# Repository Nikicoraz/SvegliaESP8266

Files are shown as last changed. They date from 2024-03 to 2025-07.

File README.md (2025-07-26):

# Sveglia ESP8266
Questa è una sveglia progettata da zero da me

### Firmware
Il firmware della sveglia è scritto in Arduino

### Hardware
L'hardware della sveglia è composto da un ESP8266, un buzzer polarizzato con un passo di 6.6mm, un display LCD 16x4 con un adattatore da parallelo a seriale I2C, un encoder e un alimentatore

### Progettazione hardware
La progettazione dell'hardware è stata svolta nel software KiCad

### Schematica
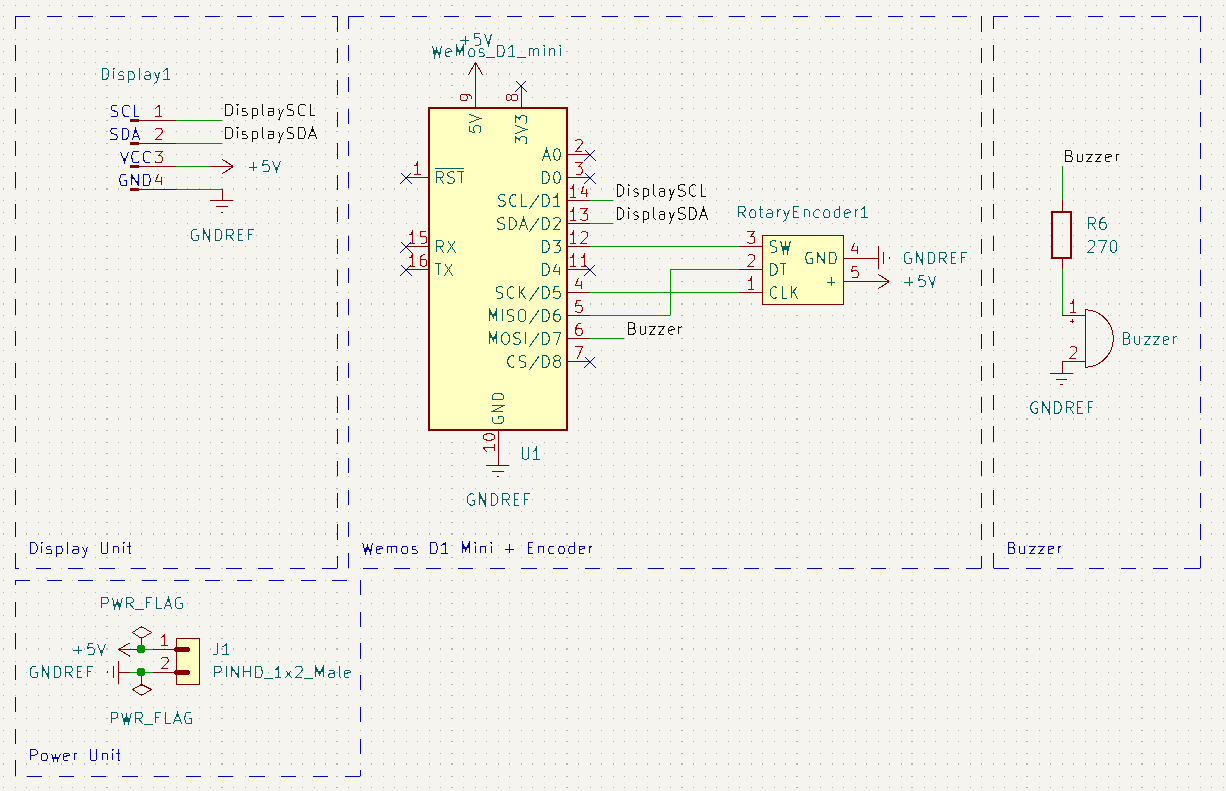
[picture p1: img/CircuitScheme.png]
Schematica


### PCB
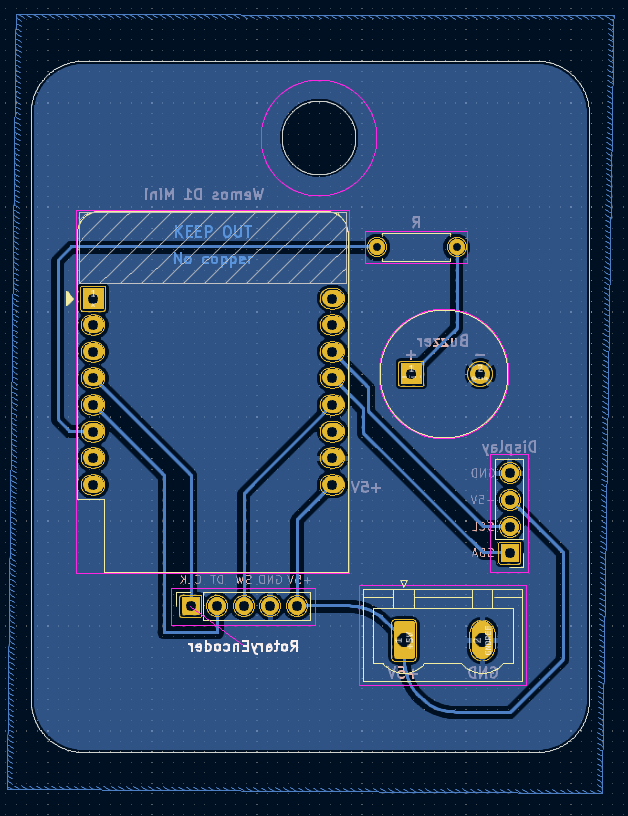
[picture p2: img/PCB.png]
PCB


Per la stampa del PCB ho utilizzato il sito [PCBWay](https://www.pcbway.com/)
### Creazione della sveglia
Dopo aver acquisito i componenti necessari e il circuito stampato, serve creare un file include/secrets.h dove bisogna inserire l'SSID e la password del Wifi e dell'hotspot e flashare l'ESP

Es.
```C
// include/secrets.h

#define SECRET_SSID "<SSID>";
#define SECRET_PASSWD "<Password>";
#define AP_PASSWD "<Password>"
```

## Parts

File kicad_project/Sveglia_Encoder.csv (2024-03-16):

# | Reference | Qty | Value | Footprint | DNP
1 | BZ1 | 1 | Buzzer
2 | D1 | 1 | LED
3 | J1 | 1 | Conn_01x04_Pin
4 | R1, R2, R3, R4, R5, R6 | 6 | 270
5 | SW1, SW2, SW3, SW4 | 4 | SW_SPST
6 | U1 | 1 | WeMos_D1_mini | Module:WEMOS_D1_mini_light

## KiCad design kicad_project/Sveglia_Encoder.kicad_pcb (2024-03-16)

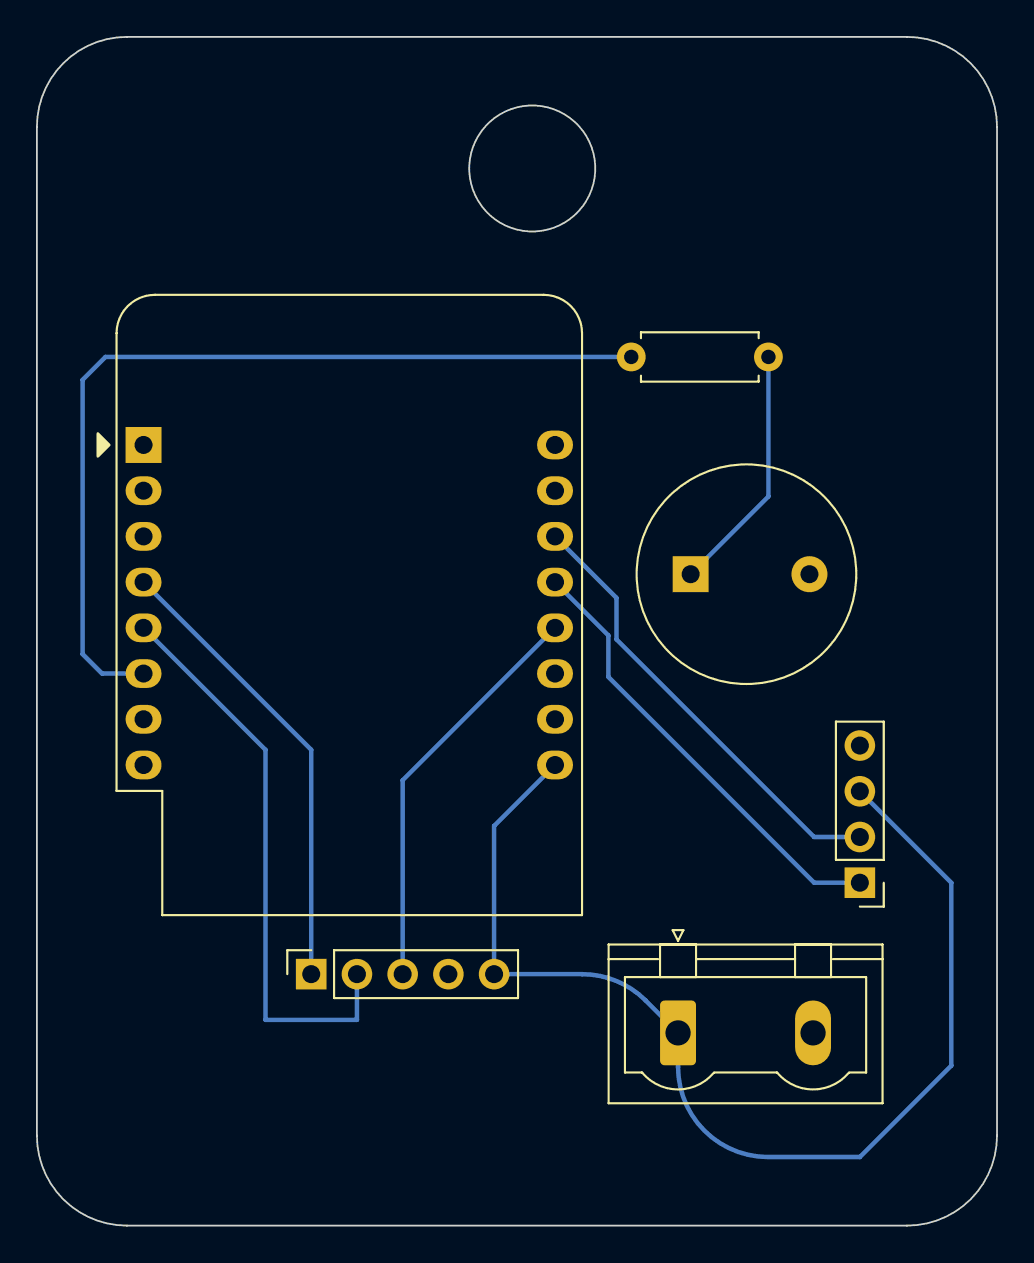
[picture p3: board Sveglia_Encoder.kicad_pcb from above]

Board: 2 copper layers, 53.3 x 66.0 mm, 6 parts (0 on the bottom side), 9 nets.

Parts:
+5V: PINHD_1x2_Male; PhoenixContact_GMSTBVA_2,5_2-G_1x02_P7.50mm_Vertical
BZ1: Buzzer; Buzzer_12x9.5RM6.6
Display: Display; PinHeader_1x04_P2.54mm_Vertical
R: 270; R_Axial_DIN0207_L6.3mm_D2.5mm_P7.62mm_Horizontal
RotaryEncoder: PinSocket_1x05_P2.54mm_Vertical
Wemos D1 Mini: WeMos_D1_mini; WEMOS_D1_mini_light

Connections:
+5V: +5V.1, Display.3, RotaryEncoder.5 (+), Wemos D1 Mini.9 (5V)
/Buzzer: R.1, Wemos D1 Mini.6 (MOSI/D7)
/DisplaySCL: Display.1, Wemos D1 Mini.14 (SCL/D1)
/DisplaySDA: Display.2, Wemos D1 Mini.13 (SDA/D2)
GNDREF: +5V.2, BZ1.2 (+), Display.4, RotaryEncoder.4 (GND), Wemos D1 Mini.10 (GND)
unnamed: BZ1.1 (-), R.2
unnamed: RotaryEncoder.1 (CLK), Wemos D1 Mini.4 (SCK/D5)
unnamed: RotaryEncoder.2 (DT), Wemos D1 Mini.5 (MISO/D6)
unnamed: RotaryEncoder.3 (SW), Wemos D1 Mini.12 (D3)

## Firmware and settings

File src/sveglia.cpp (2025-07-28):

/*

  Author: Nicola Corato
  Email: nicolacorato05@gmail.com

*/

#define SW 0    // D3 = GPIO0
#define DT D6
#define CLK D5

#include <LiquidCrystal_I2C.h>
#include <NTPClient.h>
#include <ESP8266WiFi.h>
#include <WiFiUdp.h>
#include <EEPROM.h>
#include <ArduinoOTA.h>
#include <time.h>
#include <cmath>
#include <ESP8266mDNS.h>

#include "secrets.h"
#include "menu.h"
#include "alarms.h"
#include "webserver.h"

const char* SSID = SECRET_SSID;
const char* PASSWD = SECRET_PASSWD;

// Time zone offset
const long utcOffsetInSeconds = 3600;
const bool considerLegalHour = true;

// Global time variables
byte seconds = 0;
byte minutes = 0;
byte hours = 0;
byte day = 0;
unsigned long ntpEpochTime;
unsigned long ntpStart;
bool timeSetManually = false;

char daysOfTheWeek[7][12] = { "Sunday", "Monday", "Tuesday", "Wednesday", "Thursday", "Friday", "Saturday" };

// For unset hour set to 255
byte alarmTimes[7][2] = { {255,255}, {255,255}, {255,255}, {255,255}, {255,255}, {255,255}, {255,255} };
byte nextAlarm[2] = {255, 255};
int nextDay = -1;

bool dismissNextAlarm = false;
bool alarmSounded = false;
int selectedAlarm = 0;

// Define NTP Client to get time
WiFiUDP ntpUDP;
NTPClient timeClient(ntpUDP, "europe.pool.ntp.org", utcOffsetInSeconds);

// LCD setup
const byte columns = 20;
const byte rows = 4;
LiquidCrystal_I2C lcd(0x27, columns, rows);
byte isBacklightOn = 0;
long long int backlightTimer = millis();

// Menu
MenuItem* currentMenu = nullptr;
int currentMenuLength;
int menuOption = 0;
int firstMenuOption = 0;
byte isMenuOpen = false;
int genericCouter;
bool genericCount = false;
bool genericDelay = false;
bool notConnectedMode = false;

//
// --- GENERAL FUNCTIONS ---
//

/*
  -- EEPROM STRUCTURE --
  0 (byte): EEPROM init value
  1-16 (byte[]): alarmTimes
  17-19 (byte[]): nextAlarm
  20-24 (int): nextDay
  24-28(int): selected alarm
  29 (byte): networkOverride
  29-???: networkOverrideSettings

*/

// 79 is a random prime number check
const byte EEPROMCheckValue = 79;

void generalSaveCheck(){
  byte temp;
  EEPROM.get(0, temp);
  if(temp != EEPROMCheckValue){
    EEPROM.put(0, EEPROMCheckValue);
  }
}

bool saveAlarmsToEEPROM(){
  generalSaveCheck();
  EEPROM.put(1, alarmTimes);
  EEPROM.put(17, nextAlarm);
  EEPROM.put(20, nextDay);
  return EEPROM.commit();
}

bool saveAlarmThemeToEEPROM(){
  generalSaveCheck();
  EEPROM.put(24, selectedAlarm);
  return EEPROM.commit();
}

void loadAlarmsFromEEPROM(){
  byte check = 0;
  if(EEPROM.get(0, check)){
    if(check == EEPROMCheckValue){
      // Alarm times
      EEPROM.get(1, alarmTimes);
      EEPROM.get(17, nextAlarm);
      EEPROM.get(20, nextDay);
  
      // Alarm theme
      EEPROM.get(24, selectedAlarm);
      Serial.println("Loaded alarms from EEPROM");
  
    }else{
      Serial.println("EEPROM not initialized yet");
    }
  }else{
    Serial.println("EEPROM reading failed");
  }
}

int calculateCenterTextColumnStart(int length) {
  return (columns - length) / 2;
}

int calculateCenterTextColumnStart(String text) {
  return calculateCenterTextColumnStart(text.length());
}

void centerPrint(String text, int row = 0) {
  lcd.setCursor(calculateCenterTextColumnStart(text), row);
  lcd.print(text);
}

void toggleBacklight() {
  isBacklightOn ? lcd.noBacklight() : lcd.backlight();
  isBacklightOn = !isBacklightOn;
}

void connectWifi();
bool setWifiFromWebserver(String, String);

void connectionFailed(){
  notConnectedMode = true;

  WiFi.mode(WIFI_AP);
  WiFi.softAP("ESPSveglia", AP_PASSWD);
  lcd.clear();
  centerPrint("IP: " + WiFi.softAPIP().toString(), 1);
  centerPrint("Press to set time", 2);
}

void connectWifi() {
  if(timeSetManually)
    return;

  int retries = 10;
  if(WiFi.status() != WL_CONNECTED){
    WiFi.mode(WIFI_STA);
    WiFi.setHostname("ESPSveglia"); 
    WiFi.begin(SSID, PASSWD);

    while (WiFi.status() != WL_CONNECTED && retries-- > 0) {
      delay(500);
      centerPrint("Retries: " + String(retries), 2);
      Serial.print(".");
    }

    if(retries == -1){
      centerPrint("Connection failed!", 1);
      connectionFailed();
      delay(1000);
      return;
    }else{
      notConnectedMode = false;
    }

    if(!MDNS.begin("espsveglia")) {     // Sets the esp mDNS to "espsveglia.local"
      Serial.println("Error setting up MDNS responder!");
    }

    Serial.print("Connected to ");
    Serial.println(SSID);
    Serial.print("Ip address: ");
    Serial.println(WiFi.localIP());
  }
}


// Will only be used with 31 day months
int lastSundayDay(int mday, int wday){
  if(wday != 0 && 31 - mday < 7){
    if(mday + (7 - wday) <= 31){
      return mday + (7 - wday);
    }else{
      return mday - wday;
    }
  }else{
    printf("Mday: %d\n", mday);
    printf("7 - wday: %d\naltro: %d\n", 7 - wday, 7 * (int)std::floor(((31 - mday) / 7) - 1));
    return mday + (7 - wday) + 7 * (int)std::floor(((31 - mday) / 7) - 1);
  }
}

void hourChange(){
  if (hours == 24) {
    hours = 0;
    day = (day + 1) % 7;
  }
}

void applyLegalHour(){
  hours += 1;
  hourChange();
}

void updateNTPTime() {
  if(timeSetManually)
    return;

  Serial.println("Updating time...");
  Serial.printf("Was %02d:%02d:%02d", hours, minutes, seconds);

  connectWifi();
  timeClient.begin();
  while(!timeClient.update()){
    delay(50);
    if(timeClient.forceUpdate()){   // Try to force the update since it only updates every 60 secs
      break;
    }
  } // Retry until the update succeds

  seconds = timeClient.getSeconds();
  minutes = timeClient.getMinutes();
  hours = timeClient.getHours();
  day = timeClient.getDay();
  ntpEpochTime = timeClient.getEpochTime();
  ntpStart = millis();

  if(considerLegalHour){
    // Legal hour >:(
    time_t current_time = timeClient.getEpochTime();
    struct tm* timeInfo = localtime(&current_time);
    int month = timeInfo->tm_mon;
    int mday = timeInfo->tm_mday;

    // Months have index 0
    if(month >= 3 || month <= 10){
      applyLegalHour();
    }else{
      // March
      
      int lastSunday = lastSundayDay(mday, day);
      if(month == 2){
        if(mday > lastSunday){
          applyLegalHour();
        }else{
          if(hours >= 2){
            applyLegalHour();
          }
        }
      }

      // October
      if(month == 9){
        if(mday < lastSunday){
          applyLegalHour();
        }else{
          if(hours < 3){
            applyLegalHour();
          }
        }
      }
    }
  }

  Serial.printf("Is now %02d:%02d:%02d", hours, minutes, seconds);

  timeClient.end();
}

void drawMainScreen();

void closeMenu(){
  isMenuOpen = false;
  if(((ntpEpochTime + ((millis() - ntpStart) / 1000)) / 60 ) % 60 != minutes){
    updateNTPTime();
  }
  drawMainScreen();
}

void renderMenu(MenuItem* menu, int firstOption, bool resetCursor = true) {
  lcd.clear();
  int bound = currentMenuLength > 4 ? (firstOption + 4) : currentMenuLength;
  for (int i = firstOption; i < bound; i++) {
    lcd.setCursor(0, i - firstOption);
    lcd.print(menu[i].getText().c_str());
    if (i == firstOption + 3) {
      lcd.setCursor(columns - 1, i - firstOption);
      lcd.write(0);
    }
  }
  if(resetCursor){
    lcd.cursor();
    lcd.setCursor(0, 0);
  }
}

int timeEquals(int h1, int min1, int h2, int min2){
  if(h1 == h2){
    if(min1 == min2){
      return 0;
    }else if(min1 > min2){
      return 1;
    }else{
      return -1;
    }
  }else if(h1 > h2){
    return 1;
  }else{
    return -1;
  }
}

int* getNextAlarmTime(){
  bool set = false;
  int* ret = (int*)malloc(sizeof(int) * 3);

  if(nextDay != -1){

    ret[0] = nextDay;
    ret[1] = nextAlarm[0];
    ret[2] = nextAlarm[1];
    set = true;
  }

  if(!set){
    for(int i = 0; i < 7; i++){
      int alarmHour, alarmMinutes, alarmDay;

      alarmDay = (i + day) % 7;
      alarmHour = alarmTimes[alarmDay][0];
      alarmMinutes = alarmTimes[alarmDay][1];
      if(alarmHour != 255 && (timeEquals(hours, minutes, alarmHour, alarmMinutes) == -1 || alarmDay != day)){
        ret[0] = alarmDay;
        ret[1] = alarmHour;
        ret[2] = alarmMinutes;
        set = true;
        break;
      }
    }
  }

  if(!set){
    ret[0] = 255;
  }
  
  return ret;
}

void drawMainScreen(){
  lcd.clear();
  lcd.noCursor();

  // The length of the time is always 8 chars with seconds
  lcd.setCursor(calculateCenterTextColumnStart(8), 0);
  lcd.printf("%02d:%02d:%02d", hours, minutes, seconds);


  int* nextAlarm = getNextAlarmTime();
  if(nextAlarm[0] != 255){
    centerPrint("Next alarm:", 2);
  
    char buffer[columns + 1];
    const char* dismissed = dismissNextAlarm ? "[D]" : "";
    sprintf(buffer, "%02d:%02d %s %s", nextAlarm[1], nextAlarm[2], daysOfTheWeek[nextAlarm[0]], dismissed);
    centerPrint(buffer, 3);
  }
  free(nextAlarm);
}

void changeMenu(MenuItem* menu, int length){
  currentMenu = menu;
  currentMenuLength = length;
  isMenuOpen = true;
  menuOption = 0;
  firstMenuOption = 0;
  renderMenu(currentMenu, 0);
}



void minuteChange(){
  alarmSounded = false;
  if (minutes == 60) {
    minutes = 0;
    hours += 1;
    hourChange();
  }
}

IRAM_ATTR void encoderRotateInterrupt() {
  if(genericCount){
    if(!genericDelay){    // This is because you can't do delays in functions nested too deep :(
      if(digitalRead(DT)){
        genericCouter--;
      }else{
        genericCouter++;
      }
      genericDelay = true;
    }
  }else if(isMenuOpen){
    // Change the current menu option
    if(digitalRead(DT)){
      if (menuOption > 0) menuOption--;
    }else{
      if(currentMenuLength - menuOption - 1 > 0){
        menuOption++;
      }
    }
    
    // Render menu based on the first menu option
    if(menuOption - firstMenuOption >= rows){
      firstMenuOption++;
      renderMenu(currentMenu, firstMenuOption, false);
    }else if(menuOption < firstMenuOption){
      firstMenuOption--;
      renderMenu(currentMenu, firstMenuOption, false);
    }
    lcd.setCursor(0, menuOption - firstMenuOption);
    delay(100);
  }
}

int abs(int x){
  return x > 0 ? x : -x;
}

void playAlarm(){
  MenuItem* prev;
  int length;
  if(isMenuOpen){
    prev = currentMenu;
    length = currentMenuLength;
  }
  alarmSounded = true;

  isBacklightOn = true;
  backlightTimer = millis();
  lcd.backlight();
  lcd.clear();
  centerPrint("WAKE UP!", 1);

  do{
    alarmArray[selectedAlarm]();
  }while(digitalRead(SW));

  if(isMenuOpen){
    changeMenu(prev, length);
  }
}

int* selectAlarmTime(String header = ""){
  int* ret = (int*)malloc(sizeof(int) * 2);
  genericCount = true;
  genericCouter = 0;
  lcd.clear();
  lcd.noCursor();
  if(header != ""){
    centerPrint(header);
  }else{
    centerPrint("Alarm time");
  }
  delay(200);

  int min = 0, h = 0;
  char buffer[5]; // "0" "0" ":" "0" "0" "\0"
  // Hour
  do{
    if(genericCouter < 0){
      genericCouter = 23;
    }
    h = genericCouter % 24;
    sprintf(buffer, "%02d:%02d", h, min);
    centerPrint(buffer, 1);
    delay(50);
    genericDelay = false;
  }while(digitalRead(SW));
  genericCouter = 0;
  delay(100);
  
  // Minutes
  do{
    if(genericCouter < 0){
      genericCouter = 59;
    }
    min = genericCouter % 60;
    sprintf(buffer, "%02d:%02d", h, min);
    centerPrint(buffer, 1);
    delay(50);
    genericDelay = false;
  }while(digitalRead(SW));

  genericCount = false;
  ret[0] = h;
  ret[1] = min;

  return ret;
}



void changeToMainMenu();

// 
//  --- CALLBACKS ---
//

void updateTimeCallback(){
  lcd.clear();
  lcd.noCursor();
  centerPrint("Updating time...", 1);

  updateNTPTime();
  closeMenu();
}

byte tempAlarm;
void confirmAlarmCallback();

void testAlarmCallback(){
  delay(200);
  int temp = selectedAlarm;
  selectedAlarm = tempAlarm;
  playAlarm();
  selectedAlarm = temp;
}

void changeAlarmSoundCallback();

MenuItem alarmConfirmMenu[3] = { MenuItem("Set", confirmAlarmCallback), MenuItem("Cancel", confirmAlarmCallback), MenuItem("Test", testAlarmCallback) };

const byte alarmSelectMenuLength = 7;
MenuItem alarmSelectMenu[alarmSelectMenuLength] = { MenuItem("Back", changeToMainMenu), MenuItem("Default alarm", changeAlarmSoundCallback),
                                MenuItem("Rapid fire alarm", changeAlarmSoundCallback), MenuItem("Uneven alarm", changeAlarmSoundCallback),
                                MenuItem("Scale alarm", changeAlarmSoundCallback), MenuItem("Double tone alarm", changeAlarmSoundCallback),
                                MenuItem("Complex Presents", changeAlarmSoundCallback) };

void confirmAlarmCallback(){
  if(menuOption == 0){
    selectedAlarm = tempAlarm;
    saveAlarmThemeToEEPROM();
  }
  changeMenu(alarmSelectMenu, alarmSelectMenuLength);
}

void changeAlarmSoundCallback(){
  tempAlarm = menuOption - 1;
  changeMenu(alarmConfirmMenu, 3);
}

void changeAlarmCallback(){
  changeMenu(alarmSelectMenu, alarmSelectMenuLength);
}

void alarmMenuBackCallback();
void setupAlarmDayCallback();
void removeAlarmDayCallback();

MenuItem alarmMenu[] = {
  MenuItem("Back", alarmMenuBackCallback), MenuItem("Weekdays", setupAlarmDayCallback), MenuItem("Weekend", setupAlarmDayCallback), MenuItem("Monday", setupAlarmDayCallback), 
  MenuItem("Tuesday", setupAlarmDayCallback),  MenuItem("Wednesday", setupAlarmDayCallback), MenuItem("Thursday", setupAlarmDayCallback), 
  MenuItem("Friday", setupAlarmDayCallback), MenuItem("Saturday", setupAlarmDayCallback),   MenuItem("Sunday", setupAlarmDayCallback)
};

MenuItem removeAlarmMenu[] = {
  MenuItem("Back", alarmMenuBackCallback), MenuItem("Weekdays", removeAlarmDayCallback), MenuItem("Weekend", removeAlarmDayCallback), MenuItem("Monday", removeAlarmDayCallback), 
  MenuItem("Tuesday", removeAlarmDayCallback),  MenuItem("Wednesday", removeAlarmDayCallback), MenuItem("Thursday", removeAlarmDayCallback), 
  MenuItem("Friday", removeAlarmDayCallback), MenuItem("Saturday", removeAlarmDayCallback),   MenuItem("Sunday", removeAlarmDayCallback)
};

void setupAlarmCallback(){
  changeMenu(alarmMenu, 10);
}

void setupAlarmDayCallback(){
  int selectedDay = menuOption - 1;
  int* time = selectAlarmTime();
  int h = time[0];
  int min = time[1];

  free(time);

  // Set the alarm and save to flash
  switch(selectedDay){
    case 0:
      for (int i = 0; i < 5; i++) {
        alarmTimes[i + 1][0] = h;
        alarmTimes[i + 1][1] = min;
      }
      break;
    case 1:
      alarmTimes[6][0] = h;
      alarmTimes[6][1] = min;
      alarmTimes[0][0] = h;
      alarmTimes[0][1] = min;
      break;
    case 2: case 3: case 4: case 5: case 6: case 7: case 8:
      alarmTimes[(selectedDay - 2 + 1) % 7][0] = h;
      alarmTimes[(selectedDay - 2 + 1) % 7][1] = min;
      break;
    default:
      Serial.println("How did we even get to this index??");
      exit(999);
      break;
  }

  saveAlarmsToEEPROM();
  Serial.println("Saved alarms to flash!");

  changeMenu(alarmMenu, 10);
}

void nextAlarmDaySelectCallback();

MenuItem nextAlarmTempMenu[2] = { MenuItem("Today", nextAlarmDaySelectCallback), MenuItem("Tomorrow", nextAlarmDaySelectCallback) };

void nextAlarmCallback(){
  int* time = selectAlarmTime();
  int h = time[0];
  int min = time[1];

  nextAlarm[0] = h;
  nextAlarm[1] = min; 
  free(time);

  changeMenu(nextAlarmTempMenu, 2);
}

//       |
//       |
//       ↓

void nextAlarmDaySelectCallback(){
  if(menuOption == 0){
    nextDay = day;
  }else{
    nextDay = (day + 1) % 7;
  }

  saveAlarmsToEEPROM();
  changeToMainMenu();
}

void mainTestAlarmCallback(){
  delay(200);
  playAlarm();
}

void setupWifiCallback(){
  isMenuOpen = false;
  timeSetManually = false;
  lcd.cursor_off();
  WiFi.disconnect();
  connectionFailed();
}

void dismissCallback();
void removeNextAlarmCallback();
void removeAlarmCallback();

const byte mainMenuLength = 10;
MenuItem mainMenu[mainMenuLength] = {
  MenuItem("Back", closeMenu), MenuItem("Setup alarm", setupAlarmCallback), MenuItem("Toggle next alarm", dismissCallback), MenuItem("Modify temp alarm", nextAlarmCallback), 
  MenuItem("Remove temp alarm", removeNextAlarmCallback), MenuItem("Remove alarm", removeAlarmCallback), MenuItem("Change alarm sound", changeAlarmCallback),
  MenuItem("Update time", updateTimeCallback), MenuItem("Test alarm", mainTestAlarmCallback), MenuItem("Setup wifi", setupWifiCallback)
};

void alarmMenuBackCallback(){
  changeMenu(mainMenu, mainMenuLength);
}

void removeAlarmCallback(){
  changeMenu(removeAlarmMenu, 10);
}

void removeAlarmDayCallback(){
  int selectedDay = menuOption - 1;

  // Set the alarm and save to flash
  switch(selectedDay){
    case 0:
      for (int i = 0; i < 5; i++) {
        alarmTimes[i + 1][0] = 255;
        alarmTimes[i + 1][1] = 255;
      }
      break;
    case 1:
      alarmTimes[6][0] = 255;
      alarmTimes[6][1] = 255;
      alarmTimes[0][0] = 255;
      alarmTimes[0][1] = 255;
      break;
    case 2: case 3: case 4: case 5: case 6: case 7: case 8:
      alarmTimes[(selectedDay - 2 + 1) % 7][0] = 255;
      alarmTimes[(selectedDay - 2 + 1) % 7][1] = 255;
      break;
    default:
      Serial.println("How did we even get to this index??");
      exit(999);
      break;
  }

  saveAlarmsToEEPROM();
  Serial.println("Saved alarms to flash!");

  lcd.clear();
  lcd.noCursor();
  centerPrint("Alarm removed", 1);
  delay(1000);

  changeMenu(alarmMenu, 10);
}

void removeNextAlarmCallback(){
  nextDay = -1;
  nextAlarm[0] = 255;
  nextAlarm[1] = 255;

  saveAlarmsToEEPROM();

  lcd.clear();
  lcd.noCursor();
  centerPrint("Next alarm removed", 1);
  delay(1000);

  changeToMainMenu();
}

void changeToMainMenu(){
  changeMenu(mainMenu, mainMenuLength);
}

void dismissCallback(){
  dismissNextAlarm = !dismissNextAlarm;
  lcd.clear();
  lcd.noCursor();
  if(dismissNextAlarm){
    centerPrint("Next alarm dismissed", 1);
  }else{
    centerPrint("Next alarm resumed", 1);
  }
  delay(1500);

  changeToMainMenu();
}

boolean setWifiFromWebserver(String ssid, String passwd){
  SSID = ssid.c_str();
  PASSWD = passwd.c_str();

  if(!isBacklightOn){
    toggleBacklight();
  }
  lcd.clear();
  centerPrint("Connecting to:");
  centerPrint(SSID, 1);

  WiFi.disconnect();

  connectWifi();
  if(WiFi.status() == WL_CONNECTED){
    return true;
  }else{
    return false;
  }
}

// Custom chars
byte downArrow[] = {
  B00000,
  B00000,
  B00000,
  B00000,
  B00000,
  B11111,
  B01110,
  B00100
};

void setup() {
  Serial.begin(115200);  // Start serial communication at 115200 baud
  EEPROM.begin(64);

  pinMode(buzzerPin, OUTPUT);
  pinMode(CLK, INPUT);
  pinMode(SW, INPUT_PULLUP);
  pinMode(DT, INPUT);

  // Pull-up
  digitalWrite(CLK, HIGH);
  digitalWrite(DT, HIGH);

  lcd.init();
  lcd.createChar(0, downArrow);
  toggleBacklight();
  centerPrint("Connecting...", 1);
  Serial.print("\n\nStarting...");

  loadAlarmsFromEEPROM();

  for(int i = 0; i < 7; i++){
    Serial.printf("%d: %s -> hour: %d minute: %d\n", i, daysOfTheWeek[i], alarmTimes[i][0], alarmTimes[i][1]);
  }
  Serial.printf("Next alarm -> h: %d min: %d\nNext day %d\n", nextAlarm[0], nextAlarm[1], nextDay);

  // Arduino OTA
  ArduinoOTA.onStart([] () {
    Serial.println("Started OTA");
  });

  ArduinoOTA.onEnd([]() {
    Serial.println("OTA end");
  });

  ArduinoOTA.onProgress([](unsigned int progress, unsigned int total) {
    Serial.printf("OTA update progress: %u%%\r", (progress / (total / 100)));
  });

  ArduinoOTA.onError([](ota_error_t error) {
    Serial.printf("Error[%u]: ", error);
    if (error == OTA_AUTH_ERROR) Serial.println("Auth Failed");
    else if (error == OTA_BEGIN_ERROR) Serial.println("Begin Failed");
    else if (error == OTA_CONNECT_ERROR) Serial.println("Connect Failed");
    else if (error == OTA_RECEIVE_ERROR) Serial.println("Receive Failed");
    else if (error == OTA_END_ERROR) Serial.println("End Failed");
  });

  ArduinoOTA.begin();


  // Encoder
  attachInterrupt(digitalPinToInterrupt(14), encoderRotateInterrupt, FALLING);

  setupServer(connectWifi, setWifiFromWebserver);
  connectWifi();
}

const int NTPUpdateMillisDelay = 1000 * 60 * 5;  // Update every 5 minutes

long long int prev = 0;
long long int lastTimeUpdate = -NTPUpdateMillisDelay; // It updates on the first loop cycle
byte prevSeconds = -1;
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
void loop() {
  if(notConnectedMode){
    loopServer();
    // Button press
    if(!digitalRead(SW)){
      // TODO: Manually set the time
      int* time = selectAlarmTime("Set current time");
      int h = time[0];
      int min = time[1];
      delete time;

      hours = h;
      minutes = min;
      seconds = 0;
      timeSetManually = true;
      notConnectedMode = false;
    }
  }else{
    normalLoop();
  }

  ArduinoOTA.handle();
}

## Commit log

2023-12-11 fix next alarm bug
    [sveglia.ino]
2023-12-11 First menu option bug
    [sveglia.ino]
2023-12-11 fix next alarm bug again
    [sveglia.ino]
2023-12-12 Remove LED blink
2023-12-16 Rimozione LED
2023-12-16 test alarm button
2023-12-16 Change alarm sound and bug fix
    [sveglia.ino]
2023-12-16 fix next alarm again
    [sveglia.ino]
2024-03-03 Stampa PCB
2024-03-16 Aggiunte schematiche
    [Sveglia_Encoder.csv, Sveglia_Encoder.kicad_pcb, Sveglia_Encoder.kicad_sch]
2024-04-02 next alarm calculation fix
    [sveglia.ino]
2025-07-19 mDNS and encoder fix
    [sveglia.cpp]
